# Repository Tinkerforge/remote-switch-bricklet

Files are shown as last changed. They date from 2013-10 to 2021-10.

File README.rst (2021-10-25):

Remote Switch Bricklet
======================

This repository contains the firmware source code and the hardware design
files. The documentation generator configs can be found at
https://github.com/Tinkerforge/generators

Repository Content
------------------

software/:
 * examples/: Examples for all supported languages
 * build/: Compiled files
 * src/: Source code of firmware
 * Makefile: Makefile to build project

hardware/:
 * Contains KiCad project files and additionally schematics as PDF

datasheets/:
 * Contains datasheets for sensors and complex ICs that are used

Hardware
--------

The hardware is designed with the open source EDA Suite KiCad
(http://www.kicad.org). Before you are able to open the files,
you have to install the Tinkerforge kicad-libraries
(https://github.com/Tinkerforge/kicad-libraries). You can either clone
them directly in hardware/ or clone them in a separate folder and
symlink them into hardware/
(ln -s kicad_path/kicad-libraries project_path/hardware). After that you
can open the .pro file in hardware/ with KiCad and from there view and
modify the schematics and the PCB layout.

Software
--------

If you want to do your own Brick/Bricklet firmware development we highly
recommend that you use our build environment setup script and read the
tutorial (https://www.tinkerforge.com/en/doc/Tutorials/Tutorial_Build_Environment/Tutorial.html).

To compile the C code we recommend you to install the newest GNU Arm Embedded
Toolchain (https://launchpad.net/gcc-arm-embedded/+download).
You also need to install bricklib (https://github.com/Tinkerforge/bricklib)
and brickletlib (https://github.com/Tinkerforge/brickletlib).

You can either clone it directly in software/src/ or clone it in a
separate folder and symlink it into software/src/
(ln -s bricklib_path/bricklib project_path/software/src/ and
ln -s brickletlib_path/brickletlib project_path/software/src/).
Finally make sure to have CMake installed
(http://www.cmake.org/cmake/resources/software.html).

After that you can build the firmware by invoking make in software/.
The firmware (.bin) can then be found in software/build/ and uploaded
with brickv (click button "Flashing" on start screen).

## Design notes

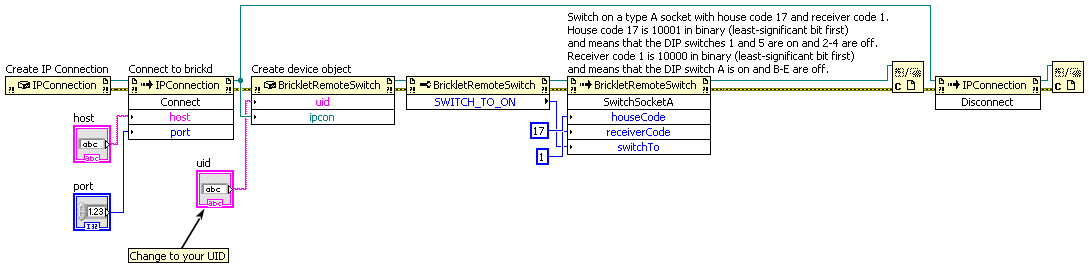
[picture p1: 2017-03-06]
software/examples/labview/Example Switch Socket.vi.png

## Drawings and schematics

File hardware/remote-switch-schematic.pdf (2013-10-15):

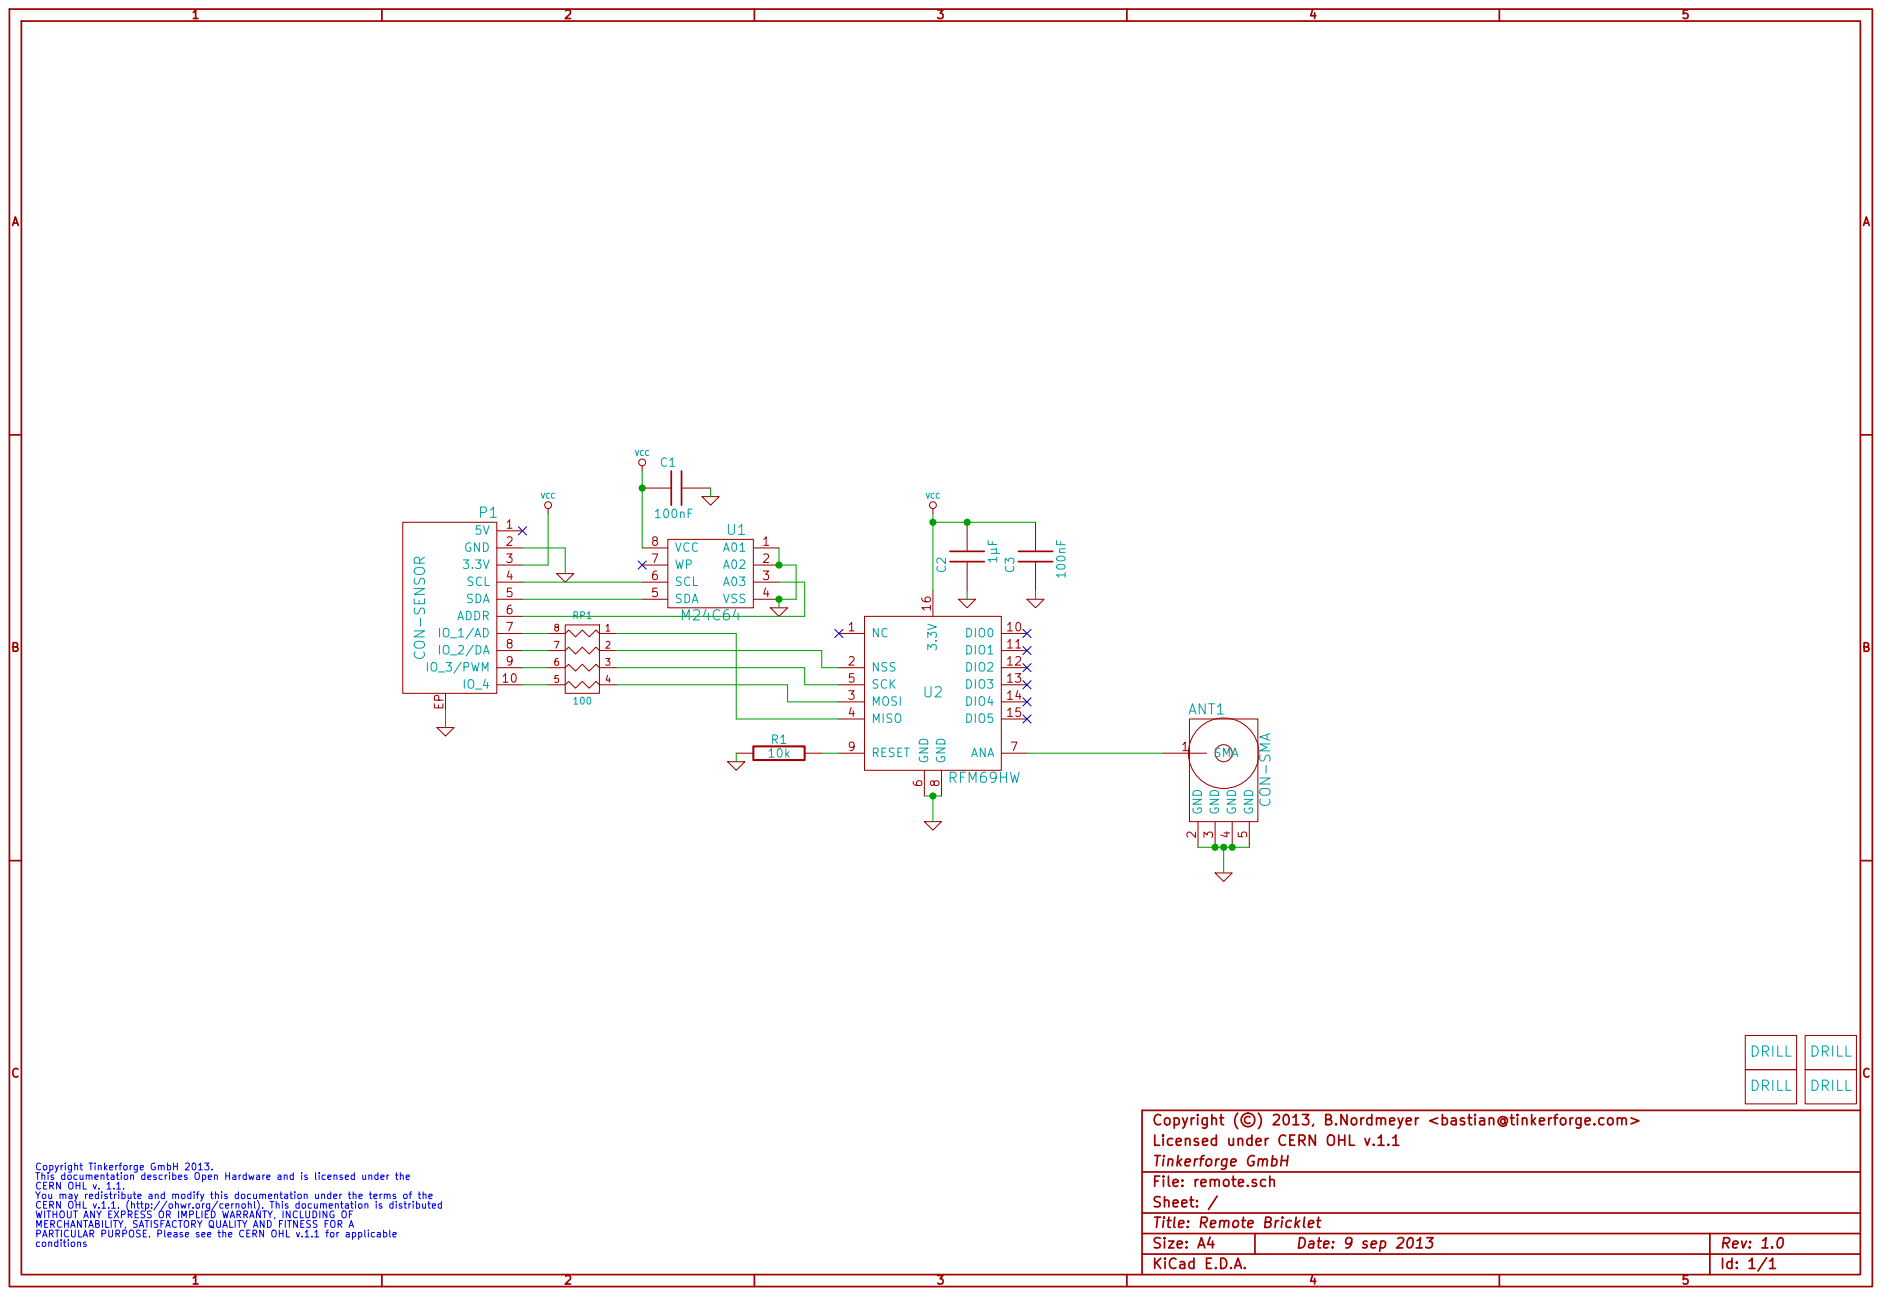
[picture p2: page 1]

VCC Copyright Tinkerforge GmbH 2013. This documentation describes Open Hardware and is licensed under the CERN OHL v. 1.1. You may redistribute and modify this documentation under the terms of the CERN OHL v.1.1. (http://ohwr.org/cernohl). This documentation is distributed WITHOUT ANY EXPRESS OR IMPLIED WARRANTY, INCLUDING OF MERCHANTABILITY, SATISFACTORY QUALITY AND FITNESS FOR A

Copyright (©) 2013, B.Nordmeyer <bastian@tinkerforge.com>
Licensed under CERN OHL v.1.1
Tinkerforge GmbH
Id: 1/1 Title: Remote Bricklet File: remote.sch Sheet: /

PARTICULAR PURPOSE. Please see the CERN OHL v.1.1 for applicable

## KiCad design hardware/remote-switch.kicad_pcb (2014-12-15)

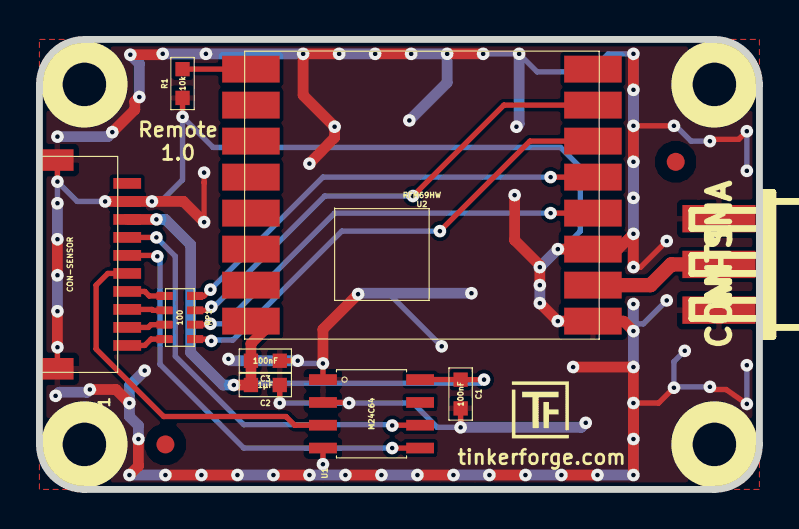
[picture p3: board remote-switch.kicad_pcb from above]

Board: 2 copper layers, 40.0 x 25.0 mm, 17 parts (0 on the bottom side), 15 nets.

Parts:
ANT1: CON-SMA
C1, C3: 100nF; 0603
C2: 1µF; 0603
Fiducial_Mark: VAL**; Fiducial_Mark
Fiducial_Mark#2: VAL**; Fiducial_Mark
P1: CON-SENSOR
R1: 10k; 0603
RP1: 100; 4X0603
U1: M24C64; SOIC8
U2: RFM69HW
U3, U4, U5, U6: DRILL; DRILL_NP
VAL: CE_5mm
VAL#2: WEEE_7mm

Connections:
GND: ANT1.2, ANT1.3, ANT1.4, ANT1.5, C1.2, C2.1, C3.1, P1.2, P1.EP, R1.1, U1.1, U1.2, U1.4, U2.6, U2.8
unnamed: R1.2, U2.9
unnamed: RP1.2, U2.2
unnamed: P1.8, RP1.7
unnamed: P1.9, RP1.6
unnamed: P1.10, RP1.5
unnamed: RP1.1, U2.4
unnamed: RP1.4, U2.3
unnamed: RP1.3, U2.5
unnamed: ANT1.1, U2.7
unnamed: P1.7, RP1.8
unnamed: P1.6, U1.3
unnamed: P1.5, U1.5
unnamed: P1.4, U1.6
VCC: C1.1, C2.2, C3.2, P1.3, U1.8, U2.16

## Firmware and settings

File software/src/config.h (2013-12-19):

/* remote-switch-bricklet
 * Copyright (C) 2013 Olaf Lüke <olaf@tinkerforge.com>
 *
 * config.h: Remote Switch Bricklet specific configuration
 *
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
 * You should have received a copy of the GNU Lesser General Public
 * License along with this library; if not, write to the
 * Free Software Foundation, Inc., 59 Temple Place - Suite 330,
 * Boston, MA 02111-1307, USA.
 */

#ifndef CONFIG_H
#define CONFIG_H

#include <stdint.h>
#include <stdbool.h>

#include "bricklib/drivers/board/sam3s/SAM3S.h"

#include "remote-switch.h"

#define LOGGING_LEVEL LOGGING_DEBUG
#define DEBUG_BRICKLET 0

#define BRICKLET_FIRMWARE_VERSION_MAJOR 2
#define BRICKLET_FIRMWARE_VERSION_MINOR 0
#define BRICKLET_FIRMWARE_VERSION_REVISION 1

#define BRICKLET_HARDWARE_VERSION_MAJOR 1
#define BRICKLET_HARDWARE_VERSION_MINOR 0
#define BRICKLET_HARDWARE_VERSION_REVISION 0

#define BRICKLET_DEVICE_IDENTIFIER 235

#define PIN_MISO (BS->pin1_ad)
#define PIN_NSS  (BS->pin2_da)
#define PIN_SCK  (BS->pin3_pwm)
#define PIN_MOSI (BS->pin4_io)

#define BOARD_MCK 64000000

#define BRICKLET_NO_OFFSET
#define INVOCATION_IN_BRICKLET_CODE

//#define RFM69_MESSAGE_LENGTH 16
#define RFM69_MESSAGE_LENGTH_MAX 64

typedef struct {
	uint8_t rfm69_data[RFM69_MESSAGE_LENGTH_MAX];
	int32_t wait;
	int32_t wait_packet;
	RFState state;
	uint8_t num_send;
	bool switching_done;

	SwitchingType current_type;
	uint8_t current_packet_length;
} BrickContext;

#endif

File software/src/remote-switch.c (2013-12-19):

/* remote-switch-bricklet
 * Copyright (C) 2013 Olaf Lüke <olaf@tinkerforge.com>
 *
 * remote-switch.c: Implementation of Remote Switch Bricklet messages
 *
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
 * You should have received a copy of the GNU Lesser General Public
 * License along with this library; if not, write to the
 * Free Software Foundation, Inc., 59 Temple Place - Suite 330,
 * Boston, MA 02111-1307, USA.
 */

#include "remote-switch.h"

#include "bricklib/utility/util_definitions.h"
#include "bricklib/utility/init.h"
#include "bricklib/bricklet/bricklet_communication.h"
#include "brickletlib/bricklet_entry.h"
#include "brickletlib/bricklet_debug.h"
#include "config.h"

const uint8_t rfm69_config[][2] = {
	{REG_FRFMSB, RF_FRFMSB_433}, // 433 Mhz
	{REG_FRFMID, RF_FRFMID_433},
	{REG_FRFLSB, RF_FRFLSB_433},
//	{REG_FDEVMSB, 0x10}, // Frequency deviation
//	{REG_FDEVLSB, 0x00},
	{REG_DATAMODUL, RF_DATAMODUL_DATAMODE_PACKET | RF_DATAMODUL_MODULATIONTYPE_OOK | RF_DATAMODUL_MODULATIONSHAPING_00}, // Use OOK
	{REG_BITRATEMSB, TYPE_A_C_BITRATEMSB},
	{REG_BITRATELSB, TYPE_A_C_BITRATELSB},
	{REG_PREAMBLEMSB, 0x00}, // no preamble
	{REG_PREAMBLELSB, 0x00},
	{REG_SYNCCONFIG, RF_SYNC_OFF}, // Use empty sync to assure small pause between commands
	{REG_SYNCVALUE1, 0},
	{REG_SYNCVALUE2, 0},
	{REG_SYNCVALUE3, 0},
	{REG_SYNCVALUE4, 0},
	{REG_SYNCVALUE5, 0},
	{REG_SYNCVALUE6, 0},
	{REG_SYNCVALUE7, 0},
	{REG_SYNCVALUE8, 0},
	{REG_PACKETCONFIG1, RF_PACKET1_FORMAT_VARIABLE | RF_PACKET1_DCFREE_OFF | RF_PACKET1_CRC_OFF},
	{REG_PAYLOADLENGTH, TYPE_A_C_PACKET_LENGTH},
	{REG_FIFOTHRESH, RF_FIFOTHRESH_TXSTART_FIFONOTEMPTY}, // Set fifo threshold, send when threshold reached
//	{REG_PALEVEL, RF_PALEVEL_OUTPUTPOWER_11111 | RF_PALEVEL_PA0_ON}, // w/o power amplifier
	{REG_PALEVEL, RF_PALEVEL_OUTPUTPOWER_11111 | RF_PALEVEL_PA1_ON | RF_PALEVEL_PA2_ON}, // w/ power amplifier: PA 1 and 2 on, 20dBm
	{REG_OCP, RF_OCP_OFF | RF_OCP_TRIM_120}, // OCP off, trimming at 120mA
	{REG_TESTPA1, 0x5D}, // High power mode (only in hw version)
	{REG_TESTPA2, 0x7C}, // High power mode (only in hw version)
	{REG_OPMODE, RF_OPMODE_STANDBY}, // Set mode to transmitter
	{REG_ENDOFCONFIG, 0}
};

const uint8_t type_registers[NUM_TYPE_CONFIGURATIONS] = {
	REG_BITRATEMSB,
	REG_BITRATELSB,
	REG_PAYLOADLENGTH,
};

const uint8_t type_configurations[NUM_TYPES][NUM_TYPE_CONFIGURATIONS] = {
	{TYPE_A_C_BITRATEMSB, TYPE_A_C_BITRATELSB, TYPE_A_C_PACKET_LENGTH},
	{TYPE_B_BITRATEMSB, TYPE_B_BITRATELSB, TYPE_B_PACKET_LENGTH},
	{TYPE_B_BITRATEMSB, TYPE_B_BITRATELSB, TYPE_B_DIM_PACKET_LENGTH},
};

void invocation(const ComType com, const uint8_t *data) {
	switch(((MessageHeader*)data)->fid) {
		case FID_SWITCH: {
			switch_socket_a(com, (SwitchSocketA*)data);
			return;
		}

		case FID_GET_SWITCHING_STATE: {
			get_switching_state(com, (GetSwitchingState*)data);
			return;
		}

		case FID_SET_REPEATS: {
			set_repeats(com, (SetRepeats*)data);
			return;
		}

		case FID_GET_REPEATS: {
			get_repeats(com, (GetRepeats*)data);
			return;
		}

		case FID_SWITCH_SOCKET_A: {
			switch_socket_a(com, (SwitchSocketA*)data);
			return;
		}

		case FID_SWITCH_SOCKET_B: {
			switch_socket_b(com, (SwitchSocketB*)data);
			return;
		}

		case FID_DIM_SOCKET_B: {
			dim_socket_b(com, (DimSocketB*)data);
			return;
		}

		case FID_SWITCH_SOCKET_C: {
			switch_socket_c(com, (SwitchSocketC*)data);
			return;
		}

		default: {
			BA->com_return_error(data, sizeof(MessageHeader), MESSAGE_ERROR_CODE_NOT_SUPPORTED, com);
			break;
		}
	}
}

void change_type(const SwitchingType type) {
	if(type == BC->current_type || type >= NUM_TYPES) {
		return;
	}

	for(uint8_t i = 0; i < NUM_TYPE_CONFIGURATIONS; i++) {
		rfm69_write_register(type_registers[i], &type_configurations[type][i], 1);
	}

	BC->current_packet_length = type_configurations[type][2];
	BC->current_type = type;
}

void switch_socket_a(const ComType com, const SwitchSocketA *data) {
	if(BC->state != RF_IDLE) {
		return;
	}

	change_type(TYPE_A_C);

	const uint8_t house_code = data->house_code;
	for(uint8_t i = 0; i < 5; i++) {
		if(house_code & (1 << i)) {
			BC->rfm69_data[i] = RFM69_DATA_ON;
		} else {
			BC->rfm69_data[i] = RFM69_DATA_FLOAT;
		}
	}

	const uint8_t receiver_code = data->receiver_code;
	for(uint8_t i = 0; i < 5; i++) {
		if(receiver_code & (1 << i)) {
			BC->rfm69_data[i+5] = RFM69_DATA_ON;
		} else {
			BC->rfm69_data[i+5] = RFM69_DATA_FLOAT;
		}
	}

	if(data->switch_to == RFM69_SWITCH_TO_ON) {
		BC->rfm69_data[10] = RFM69_DATA_ON;
		BC->rfm69_data[11] = RFM69_DATA_FLOAT;
	} else {
		BC->rfm69_data[10] = RFM69_DATA_FLOAT;
		BC->rfm69_data[11] = RFM69_DATA_ON;
	}

	// Sync
	BC->rfm69_data[12] = 0b10000000;
	BC->rfm69_data[13] = 0b00000000;
	BC->rfm69_data[14] = 0b00000000;
	BC->rfm69_data[15] = 0b00000000;

	BC->state = RF_SENDING;
	BA->com_return_setter(com, data);
}

void switch_socket_b(const ComType com, const SwitchSocketB *data) {
	if(BC->state != RF_IDLE) {
		return;
	}

	change_type(TYPE_B);

	// Sync
	BC->rfm69_data[0] = 0b00000100;
	BC->rfm69_data[1] = 0b00000000;

	// Address
	for(uint8_t i = 0; i < 26; i++) {
		if(data->address & (1 << i)) {
			BC->rfm69_data[i+2] = RFM69_DATA_B_1;
		} else {
			BC->rfm69_data[i+2] = RFM69_DATA_B_0;
		}
	}

	// Switch All
	if(data->unit == 255) {
		BC->rfm69_data[28] = RFM69_DATA_B_1;
	} else {
		BC->rfm69_data[28] = RFM69_DATA_B_0;
	}

	// On/Off
	if(data->switch_to == RFM69_SWITCH_TO_ON) {
		BC->rfm69_data[29] = RFM69_DATA_B_1;
	} else {
		BC->rfm69_data[29] = RFM69_DATA_B_0;
	}

	// Unit
	for(uint8_t i = 0; i < 4; i++) {
		if(data->unit & (1 << i)) {
			BC->rfm69_data[i+30] = RFM69_DATA_B_1;
		} else {
			BC->rfm69_data[i+30] = RFM69_DATA_B_0;
		}
	}

	// Sync
	BC->rfm69_data[34] = 0b10000000;
	BC->rfm69_data[35] = 0b00000000;
	BC->rfm69_data[36] = 0b00000000;
	BC->rfm69_data[37] = 0b00000000;
	BC->rfm69_data[38] = 0b00000000;

	BC->state = RF_SENDING;
	BA->com_return_setter(com, data);
}
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

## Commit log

2013-07-29 Initial commit of Remote Switch Bricklet firmware
2013-09-17 Add examples for Remote Switch Bricklet
2013-10-15 add hardware files
    [remote.kicad_pcb, remote.sch]
2013-12-18 Add socket type a/b API
2014-04-02 perl: Unify print style
2014-12-03 update silkscreen outlines
    [remote.kicad_pcb]
2014-12-15 updated versions with thin silkscreen lines
    [remote.kicad_pcb]
2015-08-07 Use full device class name in Python example
2016-05-18 c: Add missing device destroy call
2018-02-20 Cleanup KiCad libraries config
    Ensure LibDir=kicad-libraries and LibName1=tinkerforge.
    Remove special library.
2018-05-11 Rename files
    [remote-switch.kicad_pcb, remote-switch.sch]
2021-10-25 Update KiCad link
    https://www.kicad.org/blog/2021/10/Avoid-links-to-former-kicad-domain/
